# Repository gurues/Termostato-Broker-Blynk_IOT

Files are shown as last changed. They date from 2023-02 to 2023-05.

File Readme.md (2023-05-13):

# TERMOSTATO-BROKER

## ANTECEDENTES

Quería realizar un termostato para mis familiares y amigos que no disponen de un sistema domótico y que están un poco "verdes" con la tecnología. Debía ser lo más minimalista posible y barato.
___

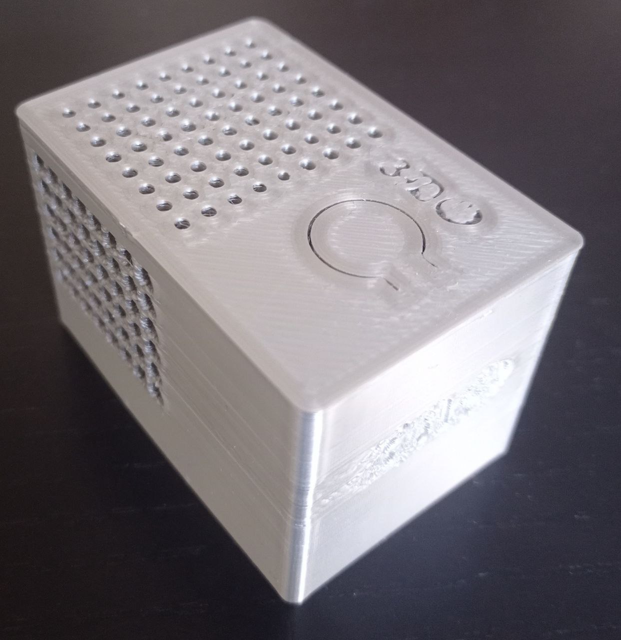
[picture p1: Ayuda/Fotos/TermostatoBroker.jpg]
TermostatoBroker


## DESCRIPCIÓN DEL PROYECTO

### Material necesario

* 1 x Wemos D1 mini (microcontrolador) ~ 3€
* Sensor de temperatura I2C SHT30 D1 mini ~ 2€
* Pulsador de control D1 mini ~ 1€
* Placa pug&play wemos D1 para conectar el hardware ~ 1€
* 1 x Shelly 1 (relé) ~ 13€
* Tener instalada la app Blynk en el móvil
* Disponer de una impresora 3D para imprimir la caja del Termostato-Broker

El Termostato-Broker cuesta en total unos 20€.

[Tienda -> Lolin Wemos D1 mini y accesorios en AliExpress](https://lolin.es.aliexpress.com/store/1331105?spm=a2g0o.detail.100005.1.593228ebGFeWij)

[Tienda -> ShellySpain](https://shellyspain.com/rele-shelly-1.html)

El Termostato-Broker controlará de forma domótica la temperatura de una vivienda mediante el arranque/paro de la caldera. Para realizar esto se programará el dispositivo de la siguiente forma:

* En el Wemos D1 mini se instala un broker mqtt que se encarga enviar las ordenes al relé de control de la calefacción además de desarrollarse todo el código de control del termostato.
* El Shelly 1, relé de control de la caldera, se debe "tasmotizar" con la versión 7.2 para que sea compatible con el Broker mqtt del Wemos D1 mini.
* Para la configuración y control del termostato domótico se dispone de una app desarrollada en [Blink](https://blynk.io/).

___

### Funcionamiento Termostato-Broker

La aplicación de control del Termostato-Broker está realizada con Blynk y mediante esta interface se puede controlar y configurar el Termostato-Broker. Los pasos a seguir para crear la app son (importante ver fotos en la carpeta Ayuda/Fotos):

* Crear un "Template".
  
  * Definir el dispositivo hardware, su conexión, en este caso ESP8266, WIFI, y obtener dos parámetros necesarios para la configuración
    de nuestro dispositivo.
    Estas líneas de código tienen que ir en la parte superior del código de control del termostato-Broker (firmware).

  ```Arduino
    #define BLYNK_TEMPLATE_ID "XXXXXXXXX"
    #define BLYNK_DEVICE_NAME "TermostatoBroker"  // Este es el nombre que he dado yo al Template
  ```

  * Definir los "Datastreams". Son los canales de comunicación entre el dispositivo y la app (Blynk.Cloud).
    En este caso usaremos los pines virtuales del ~~VO al V12~~ V0 al V9 y los definiremos para comunicar, mostrar datos y controles de
    nuestros termostato-Broker.
  * Definir un "Web Dasboard". Interface gráfica de control del dispositivo desde cualquier navegador web.
  
* Crear un nuevo "Device" a partir de un "Template", donde escogeremos el "Template" que hemos creado.
  * Obtener el "Token" para el control de ese dispositivo.

  ```Arduino
    #define BLYNK_AUTH_TOKEN "XXXXXXXXXXXXXXXXXXXXXXXXXXXXXXX"  
  ```

  * Definir un "Mobile Dasboard". Interface gráfica de control del dispositivo desde un teléfono móvil.

Una vez cargado el firmware al Wemos D1 mini cuando se alimenta por primera vez el Termstato-Broker, crea un punto de acceso WIFI llamado "Termostato_Broker_AP" para que lo configures. Una vez conectado tu PC, Tablet o móvil a esta red WIFI debes ingresar en la página <http://192.168.4.1> y configurar tus datos (red WIFI y token Blink para conectarse a la app). El Termostato-Broker se debe configurar como IP fija para que el Broker no cambie de IP y así el relé Shlelly 1 se pueda conectar siempre. Una vez hecho esto solo tienes que esperar a que el relé se conecte al Broker lo cual lo podrás ver en la app de control del dispositivo.

### Dispone de los siguientes controles

* SETPOINT. Temperatura que se desea alcanzar en la vivienda.
* RELE. Indicación del estado del relé con la configuración y datos actuales.
* ESTADO. Indicación del estado de la comunicación entre el relé y el Termostato-Broker. Siempre debe estar en verde para que el control
  sea posible. Si la comunicación se rompe el relé pasará a OFF como seguridad, apagando la calefacción.
* TEMPERATURA Y HUMEDAD ACTUAL. Son los valores de temperatura y humedad que nos indica el STH30. También podría mostrar la temperatura
  y humedad de un dispositivo externo que esté conectado al Termostato-Broker por mqtt (esto se debe configurar). Si no hay un envió de
  datos con una periodicidad menor a 5 minutos la app mostrará "No Data", indicando una anomalía en el dispositivo.
* CALEFACCION MANUAL. Este es el interruptor de AUTO/OFF de la calefacción y dependiendo de la temperatura actual y del Setpoint el relé
  arrancará o no la calefacción.
* BANDA DE FUNCIONAMIENTO. Es el intervalo en ºC de funcionamiento mínimo de la calefacción. Este parámetro es configurable y por
  defecto es 1ºC. Por ejemplo si el Setpoint es 22ºc y la Banda de Funcionamiento es 1ºC la calefacción estará arrancada desde 21ºc a
  22ºC.
* AJUSTE TEMPERATURA. Este parámetro permite ajustar el valor de la temperatura una vez contrastada la temperatura leída por el SHT30
  con otro instrumento. Este parámetro es configurable y por defecto es -3ºC.
* PROGRAMADOR HORARIO ~~1, 2 Y 3~~ 1 y 2. Se disponen de ~~3~~ 2 programadores horarios para configurar el arranque de la calefacción. En cada uno de ellos se debe poner la hora de inicio y de fin de funcionamiento que se requiere o dejar sin valor.
* CALEFACCION PROGRAMADA. Mediante este interruptor se activa la programación de la caldera, siendo el horario de funcionamiento de la
  misma lo indicado en los Programadores ~~1, 2 y 3~~ 1 y 2.
* TERMINAL. La app dispone de un terminal que muestra el estado del Termostato-Broker, del relé de la caldera y de cualquier otro
  dispositivo conectado al Broker mqtt. También dispone de una serie de órdenes para verificar el funcionamiento del dispositivo.
   (Actualmente el "Widget Terminal" está en desarrollo y pierde el histórico cada vez que se sale de la app o se actualiza)
  * Órdenes mediante terminal:
    * RESET_ALL -> Termostato-Broker configuración de fábrica.
    * RESET -> Reinicio Termostato-Broker.
    * UPDATE_OTA -> Permisivo para la actualización OTA-LOCAL.
    * RESET_RELE -> Reinicio relé Shelly 1.
    * ESTADO_RELE -> Muestra estado actual relé.
    * PROGRAMADOR -> Muestra las horas de los Programadores Horarios.
    * COMUNICACION_RELE -> Muestra/Oculta la comunicación periódica con el relé.
* El dispositivo permite la actualización por OTA desde Blynk, por lo que no es necesario estar conectado a la misma red para actualizar
  el firmware.

___

## "Tasmotizar" y configurar Shelly 1 (relé caldera)

"Tasmotizar" y configurar Shelly 1 se realizará de la siguiente forma:  (importante ver fotos en la carpeta Ayuda/Fotos)

* Actualizar o asegurarnos que el Shelly 1 tiene el firmware Tasmota 7.2. Si no es así actualizarlo a esta versión.
* Configurar el Template de Tasmota para el Shelly 1.
* Configurar mqtt. Aquí pondremos la IP del Termostato-Broker, los topic necesarios, etc.
* Configurar regla. Se configurará "Rule 1" para que si el shelly 1 no está conectado al Broker MQTT el relé esté "OFF".

```Arduino
 rule1 on Mqtt#Disconnected do power1 off endon 
```

* Poner en hora el shelly 1 mediante [comandos Tasmota](https://domotuto.com/comandos-para-introducir-en-tasmota-por-consola/)
* Para que un dispositivo "Tasmotizado" cree de nuevo un AP para volver a configurarse se le debe quitar y poner alimentación 4 veces (para la [versiones actuales de Tasmota son 7 veces](https://tasmota.github.io/docs/Device-Recovery/#program-memory)).

___

Por último comentar que en el archivo main.cpp se puede configurar las salidas DEBUG por el puerto serie y el uso de un sensor de medición de temperatura y humedad externo comunicando los datos del sensor por mqtt.

* El valor de temperatura del sensor externo llegará al Termostato-Broker mediante mqtt en el topic mqtt "sensor_temp".
* El valor de humedad del sensor externo llegará al Termostato-Broker mediante mqtt en el topic mqtt "sensor_hum".

```Arduino

// Comentar para deshabilitar el Debug de Blynk
#define BLYNK_PRINT Serial   // Defines the object that is used for printing
#define BLYNK_DEBUG        // Optional, this enables more detailed prints

//  Comentar para anular del debug serie Termostato-Broker
#define ___DEBUG___

//  Comentar para anular del debug serie correspondiente al Programador horario Termostato-Broker
#define ___DEBUG2___

// Comentar si no se dispone de sensor SHT30 y el sensor de control es externo mediante mqtt
#define sensor_sht30
```

Es importante recordar que en la parte superior del código del archivo main.cpp deben aparecer las siguientes instrucciones obtenidas al crear la app en Blynk

```Arduino
    #define BLYNK_TEMPLATE_ID "XXXXXXXXX"
    #define BLYNK_DEVICE_NAME "TermostatoBroker"  // Este es el nombre que he dado yo al Template
```

En la carpeta "AYUDA" de este proyecto se comparten fotos, diseños 3D, firmware Tasmota y archivo configuración del shelly_1 para la realización y configuración del Termostato-Broker.
___

## **Actualizado debido al cambio de política de BLYNK**

**Blynk modificó su política y redujo a 10 el número máximo de "Datastreams"**, canales de comunicación entre el dispositivo y la app (Blynk.Cloud). En la nueva versión del firm del Termostato-Broker 1.0.2, algunas de las funciones que antes se configuraban con "Datastreams" en la app, ahora se configuran con órdenes mediante el terminal de la app.

* Ordenes NUEVAS mediante terminal:
  * AJUSTE -> Muestra el ajuste de temperatura configurado.
  * AJUSTE= -> Configura ajuste de temperatura ej: AJUSTE=-2.
  * BANDA -> Muestra la banda de funcionamiento, configurado.
  * BANDA= -> Configura banda de funcionamiento, ej: BANDA=1.
  * ESTADO_MQTT -> Muestra estado actual del Broker Mqtt.

PROGRAMADOR HORARIO

Se ha reducido de 3 a 2 los programadores horarios disponibles para configurar el arranque/paro de la calefacción.

Además de las actualizaciones debidas al cambio de política de Blynk, he notado que en alguna ocasión el Broker Mqtt se quedaba "colgado", impidiendo cualquier tipo de comunicación. Para solventar esto he realizado un "watchdog" que cada 5 minutos verifica el correcto funcionamiento del Broker. Si no es así, el Termostrato-Broker se reinicia con la configuración anterior al "cuelgue".
___

## Realizado por gurues ~ Eneno 2023 ~  Actualizado Marzo 2023 (gurues@3DO ~ ogurues@gmail.com)

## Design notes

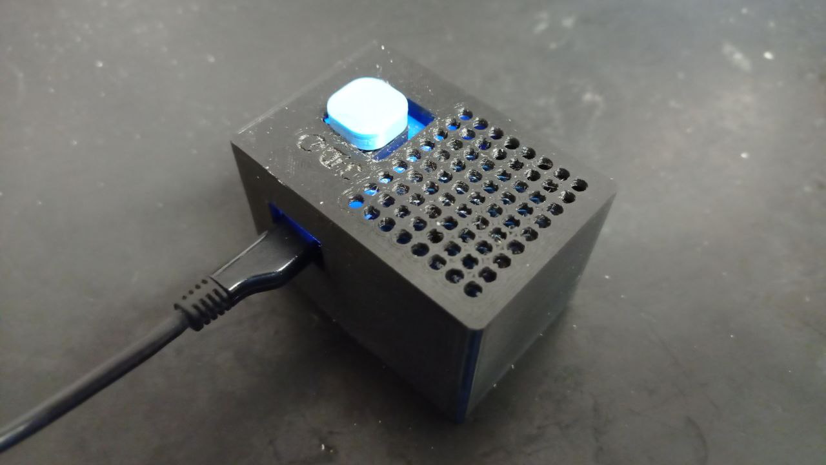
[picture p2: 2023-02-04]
Ayuda/Fotos/06-Termostato-Broker.jpg

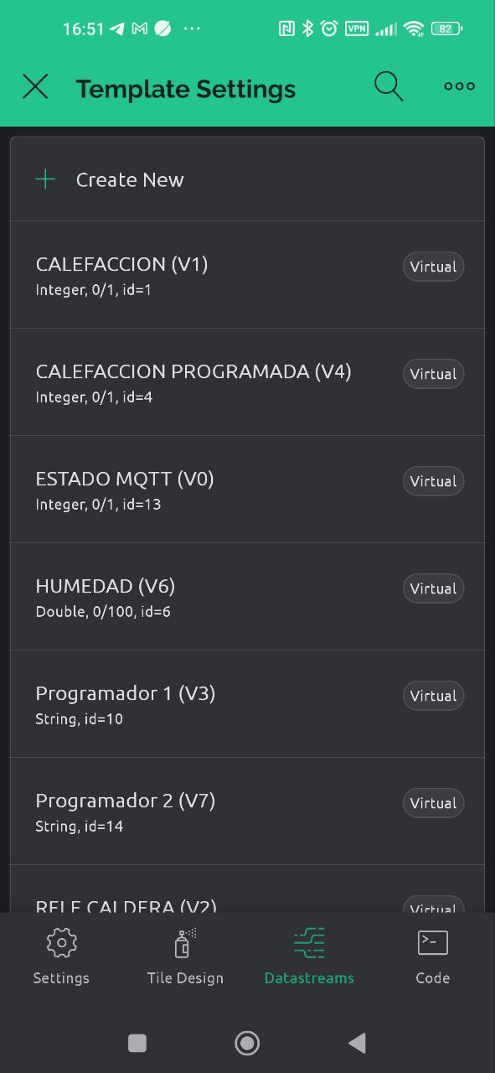
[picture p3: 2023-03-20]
Ayuda/Fotos/31-App-Blynk_1_0_2.jpg

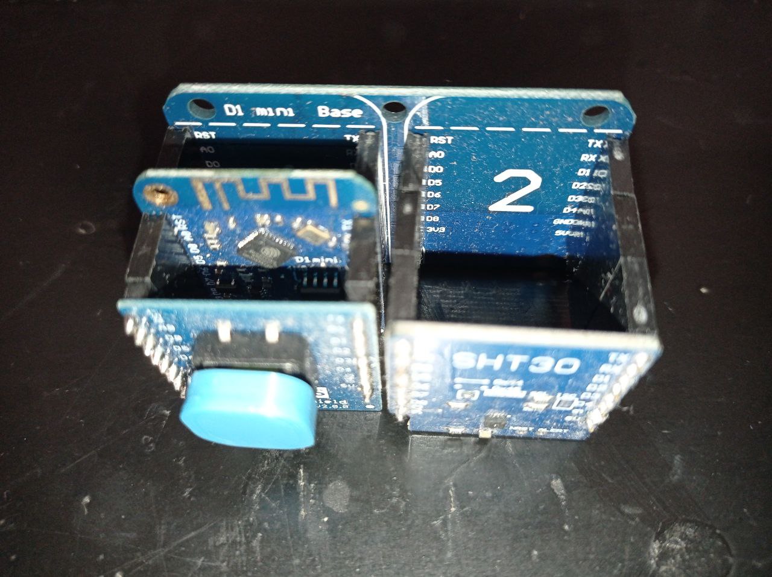
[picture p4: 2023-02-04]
Ayuda/Fotos/10-Termostato-Broker.jpg

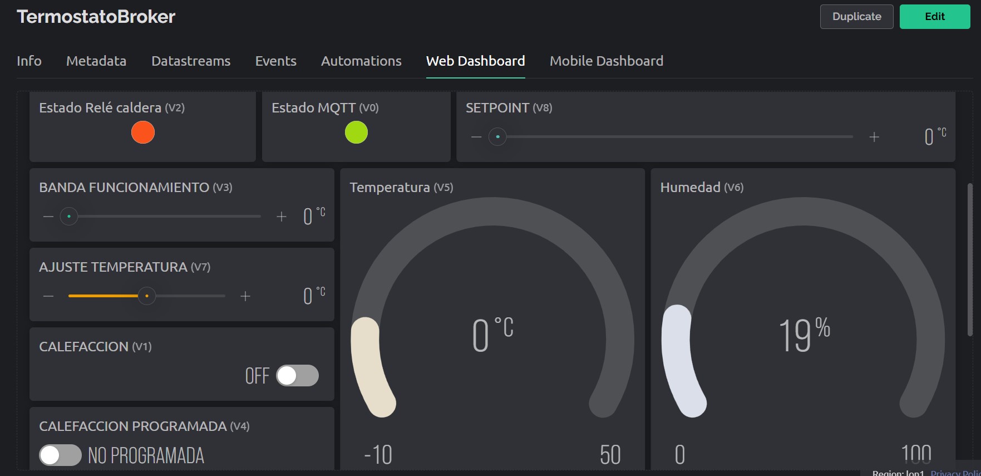
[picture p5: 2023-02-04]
Ayuda/Fotos/18-App-Blynk.jpg

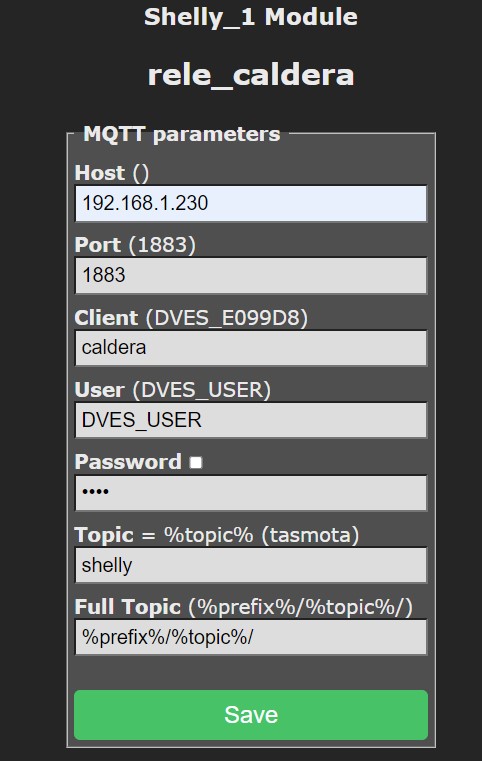
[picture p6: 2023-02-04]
Ayuda/Fotos/03-Shelly_1_Tasmota.jpg

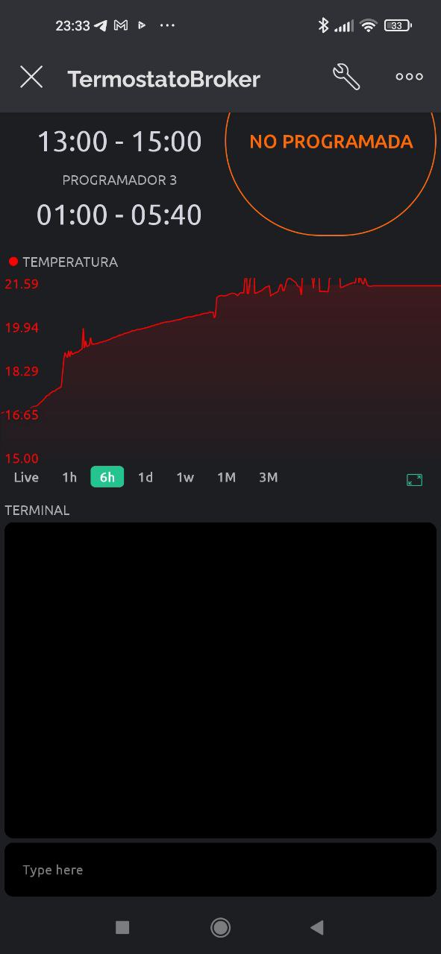
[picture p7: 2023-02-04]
Ayuda/Fotos/22-App-Blynk.jpg

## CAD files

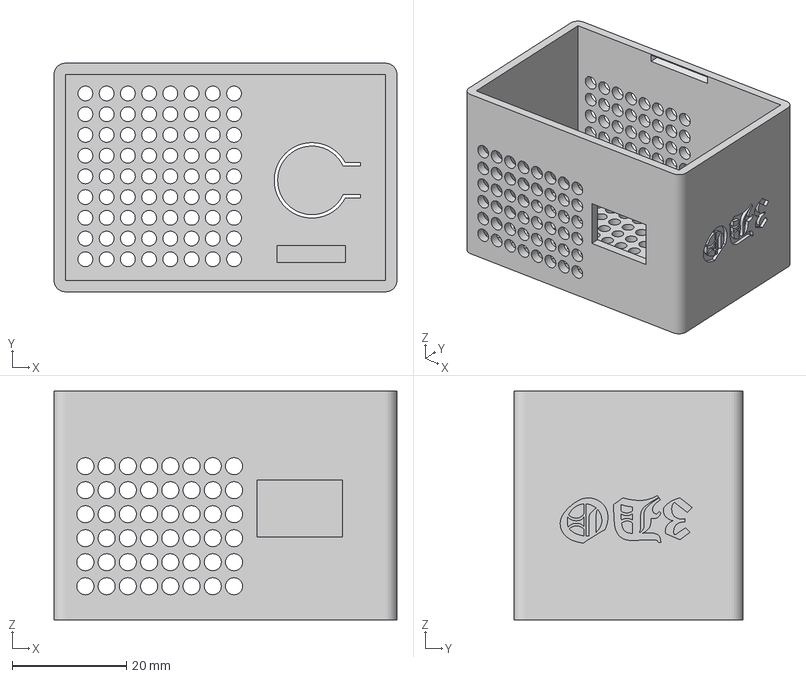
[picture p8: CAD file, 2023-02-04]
Ayuda/3D/caja_termostato_broker_2.3mf
60.0 x 40.0 x 40.0 mm

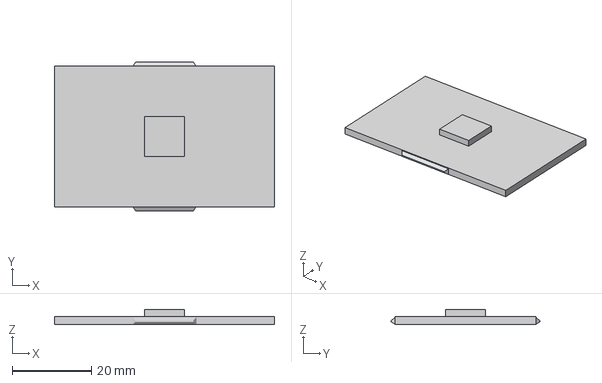
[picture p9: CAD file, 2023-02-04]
Ayuda/3D/tapa_termostato_broker.3mf
55.4 x 37.4 x 3.80 mm

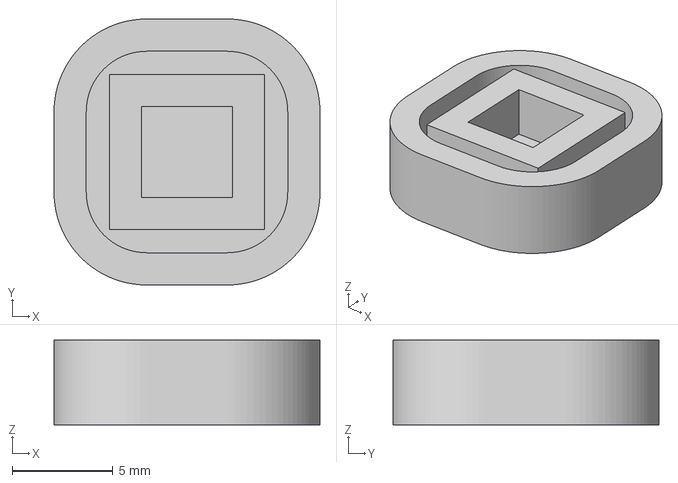
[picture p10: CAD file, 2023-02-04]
Ayuda/3D/Pulsador.3mf
13.2 x 13.2 x 4.20 mm

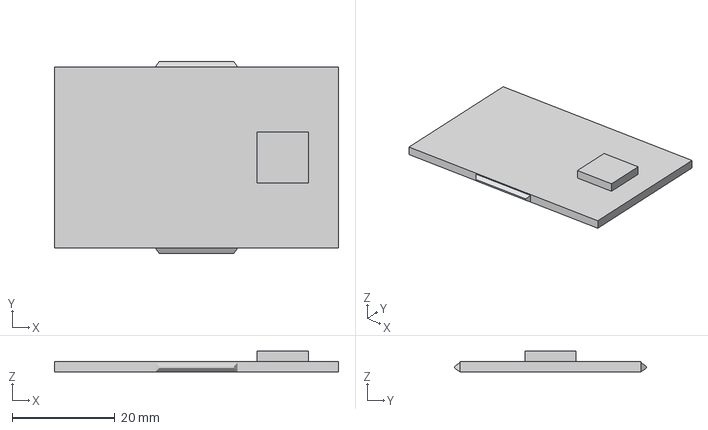
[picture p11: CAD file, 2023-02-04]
Ayuda/3D/tapa_termostato_broker_2.3mf
55.4 x 37.4 x 4.00 mm

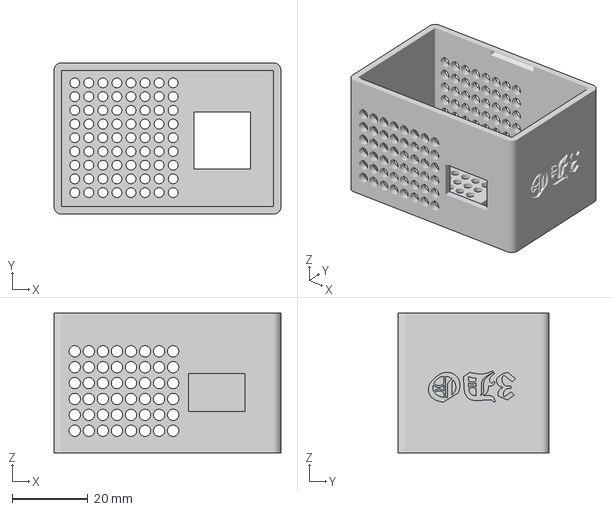
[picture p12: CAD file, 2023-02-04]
Ayuda/3D/caja_termostato_broker.3mf
60.0 x 40.0 x 37.0 mm

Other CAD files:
Ayuda/3D/Caja_Control_Temp v21.f3d
Ayuda/3D/Pulsador v6.f3d

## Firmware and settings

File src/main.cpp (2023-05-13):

/* ------------------------------------------------------------------------------------------------------------------------------
 *                            -----     Termostato-Broker     -----
 * ------------------------------------------------------------------------------------------------------------------------------
 * Este programa realiza el control de la calefacción mediante un termostato domótico. El dispositivo está formado por:
 * - Wemos D1 mini
 * - Sensor de temperatura I2C SHT30
 * - Pulsador de control
 * - Placa pug&play wemos para conectar el hardware
 * - Relé Shelly 1 como dispositivo de control final
 * En el Wemos se instala un broker mqtt que se encarga de enviar las ordenes al relé de control de la calefacción y se puede usar 
 * para la configuración del termostato. Además también se desarrolla el código de control del termostato.
 * Para la configuración y control del termostato domótico se dispone de un app desarrollada en Blink.
 *
 * ------------------------------------------------------------------------------------------------------------------------------*/

#define BLYNK_TEMPLATE_ID "XXXXXXXXXX"
#define BLYNK_DEVICE_NAME "TermostatoBroker"
#define BLYNK_FIRMWARE_VERSION  "1.0.2"

// Comentar para deshabilitar el Debug de Blynk
#define BLYNK_PRINT Serial   // Defines the object that is used for printing
//#define BLYNK_DEBUG        // Optional, this enables more detailed prints

#include <Arduino.h>
#include <ESP8266WiFi.h>
#include "Switch.h"               // Control del pulsador
#include "uMQTTBroker.h"          // Broker mqtt
#include <WEMOS_SHT3X.h>          // Sensor de temperatura
#include <BlynkSimpleEsp8266.h>   // Control externo mediante app
#include <Ticker.h>               // Temporizador funciones asincronas
#include <WidgetRTC.h>            // Fecha, dia y hora
#include <TimeLib.h>              // Fecha, dia y hora
#include <ArduinoOTA.h>           // Actualización por OTA
#include <ESP8266mDNS.h>          // Actualización por OTA
#include <WiFiUdp.h>              // Actualización por OTA
#include "LittleFS.h"             // Sistema archivos WifiManager
#include <ESPAsyncWebServer.h>    // WifiManager
#include <ESPAsyncWiFiManager.h>  // WifiManager         
#include <ArduinoJson.h>          // WifiManager  
#include <ESP8266HTTPClient.h>    // OTA a través de Blynk
#include <ESP8266httpUpdate.h>    // OTA a través de Blynk

//  Comentar para anular del debug serie Termostato-Broker
#define ___DEBUG___
//  Comentar para anular del debug serie correspondiente al Programador horario Termostato-Broker
//#define ___DEBUG2___

// Comentar si no se dispone de sensor SHT30 y el sensor de control es externo mediante mqtt
#define sensor_sht30

// IP fija Termostato Broker
IPAddress ip(192, 168, 1, 230); 
IPAddress gateway(192,168,1,1);
IPAddress subnet (255,255,255,0);
IPAddress dns1(8,8,8,8);

//Token app Blynk 
char blynk_token[34] = "BLYNK_TOKEN";

//Sensor de temperatura I2C SHT30
#ifdef sensor_sht30
  SHT3X sht30(0x45);
  float time_data = 30;     // número de segundos de muestreo del sensor de temperatura
  const int PIN_SDA = D2;                  
  const int PIN_SCL = D1; 
#endif

// Programadores de eventos Ticker
Ticker ticker_Datos, ticker_Ahora, mqttReconnectTimer, wifiReconnectTimer, watchdogSensor, watchdogBroker;

// Gestores de eventos WIFI
WiFiEventHandler wifiConnectHandler;
WiFiEventHandler wifiDisconnectHandler;

// Pulsador y led control AUTO
const int PIN_PULSADOR = D3;                                
const int PIN_LED = D4;         

// Objeto pulsador
Switch PulsadorSwitch = Switch(PIN_PULSADOR);

// WifiManager
AsyncWebServer server(80);
DNSServer dns;

    // Variables Globales
float temp_medida;                        // temperatura medida actualmente
float hum_medida;                         // humedad medida actualmente
float temp_setpoint = 21;                 // temperatura a la que se para la calefacción
int Banda_Diferencial = 1;                // intervalo de grados que está funcionando la calefacción (anterior al setpoint)
float ajuste = -3;                        // ajuste del sensor de temperatura (puede ser + o -)
int estado_calefac = 0;                   // estado calefacción -> AUTO / APAGADA
int rele_calefac = 0;                     // estado actual del rele de la calefacción (activado / desactivado)
int mem_rele_calefac = 0;                 // estado anterior del rele de la calefacción (activado / desactivado)
bool inicio = true;                       // control estado inical
bool evalua = false;                      // true -> Cuando hay que actualizar algún valor / false -> no hay nada para actualizar
bool ota = false;                         // actualización por OTA (OTA activa = true)
bool latido = false;                      // Estado rele cada 5 min (true envio activo)
bool watchdog_mqtt;                       // Perro guardiar de buen funcionamiento del Broker 
bool fabrica = false;                     // Para resetear todas las SSID del dispositio
bool shouldSaveConfig = false;            // Permisivo para guardar datos de configuración LittleFS
String client_rele_init = "caldera";      // cliente a controlar (rele shelly 1)
String client_rele;                       // cliente a controlar (rele shelly 1)
String ordenes;                           // ordenes desde la terminal de la app Blink
String overTheAirURL = "";                // URL para OTA desde Blynk

    //Variable del Programador horario
int Programador = 0;                      // Control programador
int Hora_Start_sec1;                      // Hora inicio calefacción en segundos
int Hora_Stop_sec1;                       // Hora paro calefacción en segundos
int Hora_Start_sec2;                      // Hora inicio calefacción en segundos
int Hora_Stop_sec2;                       // Hora paro calefacción en segundos
int Hora_Actual;                          // Hora actual
int Min_Actual;                           // Minuto actual
int Hora_Actual_sec;                      // Hora actual en segundos
String Hora_Start1;                       // Hora inicio Progrogramador 1
String Hora_Stop1;                        // Hora fin Progrogramador 1
String Hora_Start2;                       // Hora inicio Progrogramador 2
String Hora_Stop2;                        // Hora fin Progrogramador 2
String Prog_Dias1;                        // Dias1 programados de calefacción
String Prog_Dias2;                        // Dias2 programados de calefacción
String Dia_Actual;                        // Dia actual

    // topic dispositivo a controlar con la temperatura (en este caso relé shelly 1)
String ReleControl = "cmnd/shelly/POWER";       // Topic que comanda el relé shelly 1
String EstadoReleControl = "stat/shelly/POWER"; // Topic que muestra el estado del relé
String Dispositivo ="tele/shelly/LWT";          // Online -> Cuando está conectado al Termostato-Broker
String EstadoDispositivo = "tele/shelly/STATE"; // Estado del relé cuando está conectado al Termostato-Broker
String Watchdog = "MqttBroker";                 // Estado del Mqtt-Broker

//---------------------------------------------------------------------------------------------------------------------------------------
//              ********************  FUCIONES  ********************
//---------------------------------------------------------------------------------------------------------------------------------------

//Función que obtiene la Hora actual cada 10 segundos  --------------------------------------------------------------------
void Ahora(){

  String Domingo="0";

  Hora_Actual = hour();
  Min_Actual= minute();
  Hora_Actual_sec=(Hora_Actual*3600)+(Min_Actual*60);
  Dia_Actual= String(weekday(now())-1);
  if (Dia_Actual==Domingo){
    Dia_Actual="7";
  }
  //Dias de la semana rutina Ahora() ----------> 1.Domingo 2.Lunes 3.Martes 4.Miercoles 5.Jueves 6.Viernes 7.Sabado
  //Dias de la senama rutina Time input widge -> 1.Lunes 2.Martes 3.Miercoles 4.Jueves 5.Viernes 6.Sabado 7.Domingo
  //Es necesario acomodar el Domingo como 7

  #ifdef ___DEBUG2___
    Serial.print("DIA_Actual_Ahora: "); Serial.println(Dia_Actual);
    Serial.print("Hora_Actual: "); Serial.println(Hora_Actual); 
    Serial.print("Minuto_Actual: "); Serial.println(Min_Actual); 
    Serial.print("Hora_Actual_sec: "); Serial.println(Hora_Actual_sec);    
  #endif 

}

// Funciones app Blink  ---------------------------------------------------------------------------------------------------------

// temperatura app Blink
BLYNK_WRITE(V5){ 
  temp_medida = param.asFloat();
}

// Setpoint app Blink
BLYNK_WRITE(V8){ 
  temp_setpoint = param.asFloat();
  evalua = true;
}

// MODO MANUAL -> AUTO/APAGADA Calefacción app Blink
BLYNK_WRITE(V1){ 
  if (Programador == 0){
    estado_calefac = param.asInt();
    if (estado_calefac)
    evalua = true;
  }
}

// Objeto RTC (reloj)
WidgetRTC rtc; 

// Led estado rele
WidgetLED led(V2); 

// Led estado mqtt
WidgetLED mqtt(V0);

// Terminal
WidgetTerminal terminal(V9); 

// Ordene enviadas desde la terminal de la app Blink
BLYNK_WRITE(V9){
  ordenes = param.asStr();
}

// Horario Programador 1 app Blink
BLYNK_WRITE(V3) {
  int Hora_Start=0;
  int Min_Start=0;
  int Hora_Stop=0;
  int Min_Stop=0;
  
  // Horas programador
  TimeInputParam t(param);

  // Process start time
  if (t.hasStartTime()){
    Hora_Start = t.getStartHour(); 
    Min_Start = t.getStartMinute();
  }
  
  // Process stop time
  if (t.hasStopTime()) {
    Hora_Stop = t.getStopHour();
    Min_Stop = t.getStopMinute();
  }
  
  Hora_Start_sec1=(Hora_Start*3600)+(Min_Start*60);
  Hora_Stop_sec1=(Hora_Stop*3600)+(Min_Stop*60);

  // Process weekdays (1. Lunes 2. Martes 3. Miercoles 4. Jueves 5. Viernes 6.Sabado 7.Domingo)
  Prog_Dias1="";
  for (int i = 1; i <= 7; i++) {
    if (t.isWeekdaySelected(i)) {
      Prog_Dias1 = Prog_Dias1 + i;
    }
  }

  if (Min_Start<10){
    Hora_Start1 =  String(Hora_Start) + ":0" + String(Min_Start);
  }
  else{
    Hora_Start1 =  String(Hora_Start) + ":" + String(Min_Start);
  }
  if (Min_Stop<10){
    Hora_Stop1 = String(Hora_Stop) + ":0" + String(Min_Stop);
  }
  else{
    Hora_Stop1 = String(Hora_Stop) + ":" + String(Min_Stop);
  }

}

// Horario Programador 2 app Blink
BLYNK_WRITE(V7) {
  int Hora_Start=0;
  int Min_Start=0;
  int Hora_Stop=0;
  int Min_Stop=0;
  
  // Horas programador
  TimeInputParam t(param);

  // Process start time
  if (t.hasStartTime()){
    Hora_Start = t.getStartHour(); 
    Min_Start = t.getStartMinute();
  }
  
  // Process stop time
  if (t.hasStopTime()) {
    Hora_Stop = t.getStopHour();
    Min_Stop = t.getStopMinute();
  }
  
  Hora_Start_sec2=(Hora_Start*3600)+(Min_Start*60);
  Hora_Stop_sec2=(Hora_Stop*3600)+(Min_Stop*60);

  // Process weekdays (1. Lunes 2. Martes 3. Miercoles 4. Jueves 5. Viernes 6.Sabado 7.Domingo)
  Prog_Dias2="";
  for (int i = 1; i <= 7; i++) {
    if (t.isWeekdaySelected(i)) {
      Prog_Dias2 = Prog_Dias2 + i;
    }
  }

  if (Min_Start<10){
    Hora_Start2 =  String(Hora_Start) + ":0" + String(Min_Start);
  }
  else{
    Hora_Start2 =  String(Hora_Start) + ":" + String(Min_Start);
  }
  if (Min_Stop<10){
    Hora_Stop2 = String(Hora_Stop) + ":0" + String(Min_Stop);
  }
  else{
    Hora_Stop2 = String(Hora_Stop) + ":" + String(Min_Stop);
  }

}

// Horario Programador app Blink
BLYNK_WRITE(V4){ 
  Programador = param.asInt();
}
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
void loop(){

  // Control pulsador
  PulsadorSwitch.poll();
  // Actualización código por OTA-LOCAL
  if (ota){
    ArduinoOTA.handle();  
  }
  else {  // Resto del código del dispositivo (Termostato-Broker)
    // Me conecto a la app Blink si no estoy conectado y si no estoy actualizando por OTA
    if ((Blynk.connected()) && (!(ota)))
      Blynk.run(); // Actualización app Blynk
    if ((!(Blynk.connected())) && (!(ota)&& (!(fabrica)))){  
      startBlink();  
      // Asisgno el estado del relé al requerido por la app tras conexión
      if ((client_rele == client_rele_init) && (estado_calefac == 0)){
        myBroker.publish(ReleControl, "0", 0, 1);
        digitalWrite(PIN_LED, HIGH);
      }
      if ((client_rele == client_rele_init) && (estado_calefac == 1)){
       evalua = true; 
       myBroker.publish("cmnd/shelly/POWER", ""); // Estado del rele
      }
    }

    // ORDENES DESDE EL TERMINAL DE LA APP
    if (ordenes == "HELP"){              // Ayuda Ordes 
      ordenes = "";
      terminal.println("");
      terminal.println("ORDENES:");
      terminal.println("RESET -> Reinicio Termostato-Broker");
      terminal.println("RESET_ALL -> Termostato-Broker configuración de fábrica");
      terminal.println("UPDATE_OTA -> Permisivo para la actualización OTA-LOCAL");
      terminal.println("RESET_RELE -> Reinicio relé Shelly 1");
      terminal.println("ESTADO_RELE -> Muestra estado actual relé");
      terminal.println("ESTADO_MQTT -> Muestra estado actual del Broker Mqtt");
      terminal.println("PROGRAMADOR -> Muestra las horas de los Programadores Horarios");
      terminal.println("COMUNICACION_RELE -> Muestra/Oculta la comunicación periódica con el relé");
      terminal.println("AJUSTE -> Muestra el ajuste de temperatura configurado");
      terminal.println("AJUSTE= -> Configura ajuste de temperatura ej: AJUSTE=-2.5");
      terminal.println("BANDA -> Muestra la banda de funcionamiento, configurado");
      terminal.println("BANDA= -> Configura banda de funcionamiento, ej: BANDA=1");
      terminal.flush();
    }
    if (ordenes == "RESET"){              // RESET Termostato_Broker
      myBroker.publish(ReleControl, "0", 0, 1);
      digitalWrite(PIN_LED, HIGH);
      delay(300);
      ESP.restart();
    }
    // ORDENES DESDE EL TERMINAL DE LA APP
    if (ordenes == "RESET_ALL"){          // RESET Termostato_Broker
      terminal.println("");
      terminal.println("Conectate a la red WIFI Termostato_Broker_AP");
      terminal.println("Pon esta dirección en tu navegador http://192.168.4.1");
      terminal.println("Configura tu red WIFI y Token Blink");
      terminal.flush();
      delay(300);
      ordenes = "";
      myBroker.publish(ReleControl, "0", 0, 1);
      digitalWrite(PIN_LED, HIGH);
      fabrica = true;
      Blynk.disconnect(); // Me desconecto de Blynk
      WiFi.disconnect(true); // Me desconecto del WIFI
    }
    if (ordenes == "UPDATE_OTA"){         // Permisivo Actualización por OTA
      myBroker.publish(ReleControl, "0", 0, 1);
      digitalWrite(PIN_LED, HIGH);
      terminal.println(" Esperando actualización OTA-LOCAL");
      terminal.flush();
      delay(300);
      ota = true;
      Blynk.disconnect();
    }
    if (ordenes == "RESET_RELE"){         // RESET Relé
      ordenes = "";
      myBroker.publish("cmnd/shelly/Restart", "1");
      terminal.println("Rele Caldera Reiniciado");
      terminal.flush();
    }

    if (ordenes == "BANDA"){         // Banda de Funcionamiento
      ordenes = "";
      terminal.println(" Banda Diferencial de Funcionamiento Caldera = " + String(Banda_Diferencial));
      terminal.flush();
    }
    if (ordenes.substring(0, 6) == "BANDA="){  //  Configuración Banda de  Funcionamiento
      Banda_Diferencial = ordenes.substring(6, ordenes.length()).toInt();
      ordenes = "";
      evalua = true;
    }

    if (ordenes == "AJUSTE"){         // Ajuste Temperatura
      ordenes = "";
      terminal.println(" Ajuste Temperatura = " + String(ajuste));
      terminal.flush();
    }
    if (ordenes.substring(0, 7) == "AJUSTE="){  //  Configuración  Ajuste Temperatura
      ajuste = ordenes.substring(7, ordenes.length()).toFloat();
      ordenes = "";
      terminal.println(" Ajuste Temperatura = " + String(ajuste));
      terminal.flush();
      dataSensor();
      evalua = true;
    }
    
    if (ordenes == "ESTADO_RELE"){         // Estado Relé
      ordenes = "";
      myBroker.publish("cmnd/shelly/POWER", "");
    }

    if (ordenes == "ESTADO_MQTT"){         // Estado MQTT
      ordenes = "";
      verifico_mqtt ();
    }

    if (ordenes == "PROGRAMADOR"){         // Estado PROGRAMADORES
      ordenes = "";
      terminal.println("PROGRAMADOR 1");
      terminal.println("Inicio: " + Hora_Start1 + "h - Fin: " + Hora_Stop1 + "h");
      terminal.println("1. Lunes 2. Martes 3. Miercoles 4. Jueves 5. Viernes 6.Sabado 7.Domingo");   
      terminal.println("PROGRAMADOR 1 Dias Semana: " + Prog_Dias1);
      terminal.println("PROGRAMADOR 2");
      terminal.println("Inicio: " + Hora_Start2 + "h - Fin: " + Hora_Stop2 + "h");
      terminal.println("1. Lunes 2. Martes 3. Miercoles 4. Jueves 5. Viernes 6.Sabado 7.Domingo");
      terminal.println("PROGRAMADOR 2 Dias Semana: " + Prog_Dias2);
      terminal.flush();
    }
    if (ordenes == "COMUNICACION_RELE"){   // Comunicación periódica Relé
      ordenes = "";
      latido = !latido;
      if (latido)
        terminal.println("Activada comunicación periódica Relé");
      if (!(latido))
        terminal.println("Desactivada comunicación periódica Relé");
      terminal.flush();
    }

    // watchdog SENSOR TEMPERATURA (5 min se mantiene el error )
    if(temp_medida < -10)
      watchdogSensor.attach_scheduled(600, Fallo_Sensor);
    else
      watchdogSensor.detach();

    // Control del Programador horario de la cáldera
    if (Programador)
      Control_Programador();

    // CONTROL DEL TERMOSTATO
    if ((client_rele == client_rele_init) && (estado_calefac) && 
      ((evalua) || ((mem_rele_calefac == 0) && (rele_calefac == 0)))){   // TERMOSTATO AUTO
      digitalWrite(PIN_LED, LOW);

      if (temp_medida < temp_setpoint - Banda_Diferencial){
        inicio = false;
        if ((rele_calefac == 0) || ((mem_rele_calefac == 0) && (rele_calefac == 0))) {   // CALEFACCION ON
          #ifdef ___DEBUG___
            Serial.print("Califaccion = "); Serial.println("ON Control");
          #endif  
          mem_rele_calefac = 0;
          rele_calefac = 1;
          myBroker.publish(ReleControl, (String)rele_calefac, 0, 1);
        }
      }
      
      if (((temp_medida > temp_setpoint - Banda_Diferencial) &&   // BANDA Diferencial CALEFACCION ON SOLO AL INICIAR
          (temp_medida < temp_setpoint) && (inicio))) {  
        #ifdef ___DEBUG___
          Serial.print("Califaccion = "); Serial.println("ON Control Banda Diferencial");
        #endif  
        mem_rele_calefac = 0;
        rele_calefac = 1;
        inicio = false;
        myBroker.publish(ReleControl, (String)rele_calefac, 0, 1); 
      }

      if (temp_medida >= temp_setpoint){
        inicio = false;
        if ((rele_calefac == 1) || ((mem_rele_calefac == 0) && (rele_calefac == 0))) {   // CALEFACCION OFF
          #ifdef ___DEBUG___
            Serial.print("Califaccion = "); Serial.println("OFF Control");
          #endif
          mem_rele_calefac = 1;
          rele_calefac = 0;
          myBroker.publish(ReleControl, (String)rele_calefac);
        }
      }
      
      evalua = false;
    } 

    if (!(estado_calefac)){                             // TERMOSTATO APAGADO
      digitalWrite(PIN_LED, HIGH);
      if((client_rele == client_rele_init) && ((rele_calefac == 1) ||     
        ((mem_rele_calefac == 0) && (rele_calefac == 0)))){  // inicio
        myBroker.publish(ReleControl, "0", 0, 1);
        mem_rele_calefac = 1;
        rele_calefac = 0;
        #ifdef ___DEBUG___
          Serial.print("Califaccion = "); Serial.println("APAGADA Control");
        #endif
      }
      inicio = true;
    }
  }

}
